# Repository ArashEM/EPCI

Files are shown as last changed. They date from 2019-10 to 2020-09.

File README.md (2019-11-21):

# Introduction

I always had a dream about HW/SW co-design of network controller. Like designing schematic / PCB, then develop FW/SW and so on ...

This is basically just a dream. But for my first iteration I'd decided to design a PCI network card.

As PCI is parallel (and a little simple) protocol, so I can handle (hopefully) hardware part of network card in LX9! 

Again, my design can be as simple as 2 layer PCB. There it  is!

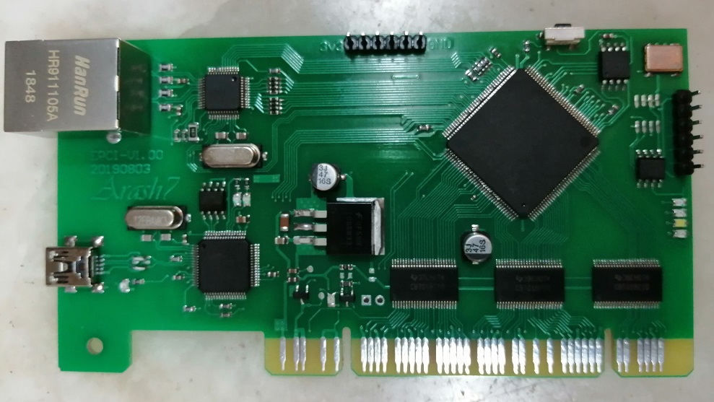
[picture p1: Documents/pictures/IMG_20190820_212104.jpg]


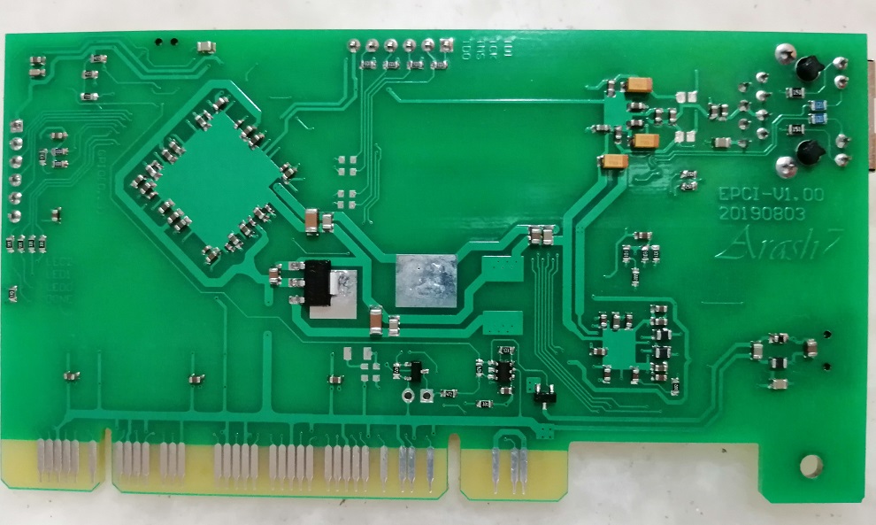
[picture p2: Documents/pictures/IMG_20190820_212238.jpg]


# Specification

First of all, main idea of board came from **MESA-5I25** board from [mesanet.com](http://www.mesanet.com/fpgacardinfo.html). I've learn alot from their board (only it's pictures, I've never have one) and HDLs they provide for board.

- Universal PCI interface (5v0, 3v3)
- XC6SLX9-2TQG144I
- DP83848 (Ethernet PHY with MII interface to FPGA)
- W25Q64FV (32Mb x4 flash)
- FT2232H (As USB to serial and JTAG interface)

# Development 

I'm still working on HDLs. codes on FW/SRC  are simple demo for board functionality which:

- Provide 256 bytes BRAM in **first** 256 bytes of `BAR0`
- Provide 1 byte general output register in **second** 256 bytes of `BAR0` which control 3x LED on board

I've tested MII/MDIO interface via MicroBlaze soft core. They are working.

Here is my development setup:



Motherboard I'm using, is an old `G41M-E2SL` which runs Ubuntu-16.04 from **PXE/NFS**. So I have full control over kernel, initrd and rootfs. 

Check `Documents\pxe-menu` 

# Notes

1. If you want to use this board, as I and my good friend said: **Check it yourself** !
2. And ... Have fun ...

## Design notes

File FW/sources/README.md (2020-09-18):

# Introduction

This folder contains EPCI project firmwares. Which include HDLs for FPGA and C code for Linux device driver.

- `hdl` includes all HDL files to build **BIT** for EPCI-V1.0X board
- `driver` include all C files to build **.ko** file which is EPCI-V1.0X Linux driver

## Synthesis prerequisites 

To build (synthesis / Implement) HDL files, you need:

- Installed <u>Xilinx ISE tools</u>. I've tested HDLs with ISE-14.07 
- Installed <u>GNU make</u> utility 

Then

```bash
git clone https://github.com/ArashEM/EPCI.git
cd EPCI/FW/sources/hdl/
make mcs
```

You can find programming files in `build/epci_fpga.bit` , `build/epci_fpga.mcs`

## Compile prerequisites

To compile EPCI Linux driver, you need:

- Linux headers (According to your Distro. Linux kernel version). I've tested it under Ubuntu-16.04 with kernel *4.4.0-116-generic #140*.
- `gcc`

Then

```bash
git clone https://github.com/ArashEM/EPCI.git
cd EPCI/FW/sources/driver/
make 
```

You can find kernel module in `build/epci.ko`

# How to change

Synthesizing HDLs is based on [ISE-Makefile](https://github.com/duskwuff/Xilinx-ISE-Makefile.git)  project with a little modifications. 

First of all, check `configs/project.cfg` file which include all HDLs and synthesis options. You do not need to make any changes in `Makefile`. 

Kernel module build is traditional Linux Kbuild system. For more information you can check [lkmpg](https://www.tldp.org/LDP/lkmpg/2.6/lkmpg.pdf). 

# Jenkins

`Jenkinsfile` in this directory is about to implement **hardware in loop** tests via two salve node (`ise-0` and `dh-01`). It contains following stages:

1. `checkout` : clone repository in **master** node and stash it for further use
2. `build`: This stage is parallel build stage which compile *kernel module* in **dh-01** node. It also generate *bitfile* in **ise-01** node. I will explain more about these nodes. In this stage some *test applications* are compiled too.
3. `deploy`: This stage deploy build artifacts (*bitfile* and *driver*) in real setup. With help of `openocd` I could program FPGA in Linux. Some scripts are developed for ease of deployment process.
4. `test`: After *bitfile* is loaded to FPGA and device driver is ready to use, test application in run to ensure that whole chain is working fine. 

## slave node `ise-01`

`ise-0` is Windows/Linux  slave (virtual) machine which is used to generate *bitfile*/*mcs* for EPCI-V1.0x FPGA. This node includes:

- Installed <u>Xilinx ISE tools</u>. I've tested HDLs with ISE-14.07 
- Installed <u>GNU make</u> utility 

Make sure Jenkins has proper access to use Xilinx ISE tools. 

## slave node `dh-01`

`dh-0` is Linux **physical** machine with PCI slot which is used to compile device driver and test *EPCI-V1.0x* board. This includes: 

- Linux headers (According to your Distro. Linux kernel version). I've tested it under Ubuntu-16.04 with kernel *4.4.0-116-generic #140*.
- `gcc` : for compiling driver and test applications
- `openocd`: for programming FPGA (check `hdl/scripts/epci-openocd.cfg`). As you know *EPCI-V1.0x* has an on board JTAG (`HS-2`) programmer which is connected to `dh-0` via USB cable 
- `sudoer` access for *jenkins* user (controlled by **master** node) to use `insmod` and `rmmod`  (check `driver/scripts/epci_load`)
- *EPCI-V1.0x* board is installed in one of PCI slot of `dh-01`. 

As you can see `dh-01` is used for build as well as test bed for *EPCI-V1.0x*. It's an **Asus G41M-E2SL** motherboard which I described in project top level `README.md` file.

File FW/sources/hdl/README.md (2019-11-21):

# Introduction

HDL part of project can be found here. File hierarchy is and folder content is described below

- `components`: containing all HDL components of project
- `configs`: includes Makefile configuration files and other configuration files
- `constraints`: UCF and other constraint fils
- `packages`: All required packages for VHDL files to be synthesized 
- `build`: build artifacts like **mcs** file can be found here

# Architecture

EPCI implements only `BAR0` with **64KB** of  non-prefetchable memory space. Here is result of `lspci` command in G41 board

```bash
root@G41MES2L:/home/me# lspci -xxxvv -s 03:01.0
03:01.0 DPIO module: Xilinx Corporation Xilinx 6 Designs (Xilinx IP) (rev 02)
        Subsystem: Xilinx Corporation Xilinx 6 Designs (Xilinx IP)
        Control: I/O- Mem+ BusMaster- SpecCycle- MemWINV- VGASnoop- ParErr- Stepping- SERR- FastB2B- DisINTx-
        Status: Cap- 66MHz- UDF- FastB2B- ParErr- DEVSEL=medium >TAbort- <TAbort- <MAbort- >SERR- <PERR- INTx-
        Interrupt: pin A routed to IRQ 11
        Region 0: Memory at e1500000 (32-bit, non-prefetchable) [size=64K]
00: ee 10 00 06 02 00 00 02 02 00 00 11 00 00 00 00
10: 00 00 50 e1 00 00 00 00 00 00 00 00 00 00 00 00
20: 00 00 00 00 00 00 00 00 00 00 00 00 ee 10 00 06
30: 00 00 00 00 00 00 00 00 00 00 00 00 00 01 00 00

```

## Memory map

Internal memory map of EPCI firmware is described in following table. All offsets are according to `BAR0` address.

| offset | size (B) | description |
| --- | --- | --- |
| `0x0000` | `0x8000` | **32KB** of SRAM. can be used for Read/Write test operation. byte, word and dword access is implemented. |
| `0x8010` | `0x10` | Register map for **LEDs** controller. Details of register is listed below |

##  LED controller 

`EPCI-V1.00` hardware had 3 LEDs. each LED has it's own controller with 32 bit control registers.

| offset | size (B) | description |
| --- | --- | --- |
| `0x0`  | `0x1` | (x,x,x,x,x,x,x, `on/off`). Control LEDx on/off status |
| `0x1`  | `0x1` | For future used |
| `0x2`  | `0x02` | PWM value |

For more information check `hdl/components/LED.vhd`

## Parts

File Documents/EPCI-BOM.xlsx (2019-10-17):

Value | Quantity | Footprint | Description | Designator | Available | Shop
100nF | 17 | 0603PKG | Capacitor | C1, C2, C3, C4, C10, C11, C12, C13, C15, C16, C17, C19, C20, C36, C83, C85, C86 | YES
1.5nF | 1 | C0805 | Capacitor | C5 | YES
27pF | 2 | C0805 | Capacitor | C6, C7 | YES
10uF | 3 | 3216X18N | Polarized Capacitor (Surface Mount) | C8, C9, C14 | YES
1uF | 1 | 0603PKG | Capacitor | C18 | YES
100nF | 9 | C0805 | Capacitor | C21, C22, C25, C29, C33, C34, C35, C81, C88 | YES
10uF | 1 | C0805 | Capacitor | C23 | YES
22uF | 3 | C1206 | Capacitor | C24, C28, C87 | YES
47uf | 2 | Capacitor |  | C26, C27 | YES
100nF | 14 | 0603PKG | Capacitor (Semiconductor SIM Model) | C30, C31, C32, C38, C39, C40, C41, C43, C44, C45, C47, C49, C52, C82 | YES
3.3uF | 1 | C0805 | Capacitor | C37 | NO | JAVAN
10uF | 1 | 0603PKG | Capacitor (Semiconductor SIM Model) | C42 | YES
4.7uF | 20 | 0603PKG | Capacitor (Semiconductor SIM Model) | C46, C48, C54, C55, C56, C57, C58, C59, C60, C62, C63, C64, C67, C68, C69, C70, C75, C76, C79, C80 | NO | IC-KALA
27pF | 2 | 0603PKG | Capacitor | C50, C51 | YES
470n | 10 | 0402 | Capacitor (Semiconductor SIM Model) | C53, C61, C65, C66, C71, C72, C73, C74, C77, C78 | NO | IC-KALA
47nF | 1 | 0603PKG | Capacitor | C84 | YES
 | 8 | C0805 | Typical INFRARED GaAs LED | D1, D2, D3, D4, D5, D6, D7, D8 | YES
 | 1 | C1206 | Zener Diode | D9 | NO | KA
 | 1 | PCI-32bit-5/3.3V-V2.2 | PCI-32bit-5/3.3V-V2.2 | J1 | YES
10mH | 4 | C0805 | Inductor | L1, L2, L3, L4 | YES
 | 1 | RJ45 |  | LAN1 | YES
 | 1 | HDR1X2 | Header, 2-Pin | P1 | YES
 | 1 | Mini USB |  | P2 | YES
 | 1 | HDR1X6 | Header, 6-Pin | P3 | YES
 | 1 | HDR1X6 | Header, 6-Pin | P4 | YES
 | 2 | SOT23 | N-Channel Power MOSFET | Q1, Q4 | NO | JAVAN | IRLML2502
 | 2 | SOT23 | P-Channel Power MOSFET | Q2, Q3 | NO | JAVAN
0R_DNP | 2 | C0805 | Semiconductor Resistor | R1, R2 | YES
50 | 4 | C0805 | Semiconductor Resistor | R3, R4, R5, R6 | YES
220R | 2 | 0603PKG | Semiconductor Resistor | R7, R51 | NO | JAVAN
120R | 2 | C0805 | Semiconductor Resistor | R8, R9 | YES
220R | 3 | ARA4x0603 |  | R10, R13, R52 | NO | KA
150R | 2 | C0805 | Semiconductor Resistor | R11, R12 | YES
1.5K | 2 | 0603PKG | Semiconductor Resistor | R14, R15 | NO | JAVAN
2.2K | 3 | 0603PKG | Semiconductor Resistor | R16, R17, R38 | NO | JAVAN
4.87K | 1 | C1206 | Semiconductor Resistor | R18 | YES
10K | 12 | 0603PKG | Semiconductor Resistor | R20, R23, R33, R34, R35, R42, R43, R44, R45, R57, R58, R62 | YES
330 | 7 | 0603PKG | Semiconductor Resistor | R21, R30, R36, R37, R59, R60, R61 | YES
470K | 1 | 0603PKG | Semiconductor Resistor | R22 | NO | JAVAN
4.7K | 7 | 0603PKG | Resistor | R24, R25, R40, R53, R54, R55, R56 | YES
22R | 4 | 0603PKG | Semiconductor Resistor | R26, R27, R28, R29 | YES
1K0 | 1 | 0603PKG | Semiconductor Resistor | R31 | YES
12K0 | 1 | 0603PKG | Semiconductor Resistor | R32 | NO | JAVAN
0R | 2 | 0603PKG | Resistor | R39, R64 | YES
330R | 1 | 0603PKG | Resistor | R41 | YES
30R | 1 | 0603PKG | Resistor | R46 | NO | JAVAN | 33R
0R_DNP | 3 | 0603PKG | Resistor | R63, R65, R66 | YES
 | 1 | SMD push button | Switch | S1 | YES
 | 1 | LQFP48 |  | U1 | YES
 | 1 | SOT23-6 | Low Loss PowerPath™ Controller in ThinSOT | U2 | YES
 | 1 | TO263 |  | U3 | YES
 | 1 | SOT223 | 1A Adjustable/Fixed Low Dropout Linear Regulator | U4 | NO | JAVAN | AMS1117
 | 3 | TSSOP-48-DGG | 20-BIT FET BUS SWITCH WITH LEVEL SHIFTING | U5, U6, U7 | YES
 | 1 | SOT457 | TVS Zener | U8 | NO | JAVAN | PRTR5V0U2D
 | 1 | 8S1_N | 1Kbit (128 x 8 or 64 x 16), 3-wire Bus Serial Automotive EEPROM, 2.5V, 8-Pin SOIC, Bulk | U9 | YES
 | 1 | LQFP-64_N | Dual High Speed USB To Multipurpose UART/FIFO IC, 64-pin LQFP, Tape and Reel | U10 | YES
 | 1 | TQG144 | Xilinx Spartan6 LX9 | U11 | YES
 | 1 | SSOP8 | W25Q32FVSSIG | U12 | NO | JAVAN
 | 1 | Crystal5x7 |  | U13 | YES
 | 1 | 8S1_N | Digital Temperature Sensor and Thermal Watchdog with Two-Wire Interface, 8 pin MINI SOIC | U14 | NO | ?
 | 1 | 8S1_N | 1Kbit (128 x 8), 2-wire Bus Automotive Serial EEPROM with Write Protect, 2.5V, 8-Pin SOIC, Bulk | U15 | YES
25Mhz | 1 | SMD_Crystal | Crystal Oscillator | Y1 | NO | JAVAN
12Mhz | 1 | SMD_Crystal | Crystal Oscillator | Y2 | NO | IC-KALA

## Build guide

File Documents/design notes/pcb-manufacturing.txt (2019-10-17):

https://www.slideshare.net/epectec/how-to-build-a-circuit-board-boot-camp

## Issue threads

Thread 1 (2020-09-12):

multiple read from /dev/epci-mem cause BAR0 to clear

ArashEM, 2020-09-12:
While EPCI is working, by multiple reading form `/dev/epci-mem`, BAR0 become `0x00`
Here is evidence for it:
```
root@G41MES2L:~# hexdump -C -n 256 /dev/epci-mem
00000000  00 00 00 00 00 00 00 00  00 00 00 00 00 00 00 00  |................|
*
00000100
root@G41MES2L:~# hexdump -C -n 256 /dev/epci-mem
00000000  ff ff ff ff ff ff ff ff  ff ff ff ff ff ff ff ff  |................|
*
00000100
```
After calling `hdl/scripts/epci_configure` everything works fine

ArashEM, 2020-09-12:
By using `pcie_debug`, multiple read from memory cause no problem.
`pcie_debug` use `/sys/bus/pci/devices/0000\:03\:01.0/resource0` to access **BAR0**.
Maybe there is some issue with `/dev/epci-mem`!

ArashEM, 2020-09-13:
Is it sort of **reset**?
Why would `BAR0` become zero during reading via `hexdump`?
At first I should clear problem source
- FPGA firmware
- Kernel driver
- Both!!

ArashEM, 2020-09-13:
This pattern is interesting too
```
root@G41MES2L:/home/me/EPCI/FW/sources/hdl# hexdump /dev/epci-mem
0000000 0000 0000 0000 0000 0000 0000 0000 0000
*
0000380 ffff ffff 0000 0000 ffff ffff ffff ffff
0000390 ffff ffff ffff ffff ffff ffff ffff ffff
*
0008000
```
Seem `BAR0` is some how malfunctioning

ArashEM, 2020-09-13:
And this one too
Healthy:
```
root@G41MES2L:/home/me/EPCI/FW/sources/hdl# hexdump -n 1024 /dev/epci-mem
0000000 e816 f000 e816 f000 e2c3 f000 e816 f000
0000010 e804 f000 ff54 f000 70a8 f000 e816 f000
0000020 fea5 f000 e987 f000 ef6f f000 ef6f f000
0000030 ef6f f000 ef6f f000 ef57 f000 ef6f f000
0000040 0014 c000 f84d f000 f841 f000 ec59 f000
0000050 e739 f000 f859 f000 e82e f000 efd2 f000
0000060 e7a4 f000 e6f2 f000 fe6e f000 ff53 f000
0000070 ff53 f000 f0a4 f000 efc7 f000 7c81 c000
0000080 e816 f000 e816 f000 e816 f000 e816 f000
*
0000100 ec59 f000 87b0 f000 f065 f000 7881 c000
0000110 e816 f000 e816 f000 87b0 f000 e816 f000
0000120 e816 f000 e816 f000 e816 f000 e816 f000
*
0000140 ef6f f000 e816 f000 e816 f000 e816 f000
0000150 e816 f000 e816 f000 e816 f000 e816 f000
*
0000180 0000 0000 0000 0000 0000 0000 0000 0000
*
00001a0 e816 f000 e816 f000 e816 f000 e816 f000
00001b0 e816 f000 0014 c000 e816 f000 e816 f000
00001c0 fcac f000 ecf3 f000 ef6f f000 9f00 f000
00001d0 ee5d f000 f0fc f000 ed00 f000 ed24 f000
00001e0 0000 0000 0000 0000 0000 0000 0000 0000
*
0000360 0000 0000 0000 0000 0000 743e 44c3 eee7
0000370 fed1 e806 0001 1000 0000 038e 0000 eee7
0000380 1801 0f00 0050 0601 0700 7626 1800 1800
0000390 d000 0050 03d4 0000 fed1 43da 0001 00ff
00003a0 0000 0001 f880 0007 d000 0e0a 0000 0260
00003b0 d000 0246 0000 fca0 f000 fca3 0670 0000
00003c0 9800 0707 d000 0212 0040 0000 0cd0 005e
00003d0 0000 0000 f000 f000 0050 0000 43da 0000
00003e0 00ff 0000 f8d8 0cd0 0cd3 4451 f000 0802
00003f0 43da 4420 50aa 477d 4603 0809 4524 0009
0000400
```
Malfunctioning
```
root@G41MES2L:/home/me/EPCI/FW/sources/hdl# hexdump -n 1024 /dev/epci-mem
0000000 e816 f000 e816 f000 e2c3 f000 e816 f000
0000010 e804 f000 ff54 f000 70a8 f000 e816 f000
0000020 fea5 f000 e987 f000 ef6f f000 ef6f f000
0000030 ef6f f000 ef6f f000 ef57 f000 ef6f f000
0000040 0014 c000 f84d f000 f841 f000 ec59 f000
0000050 e739 f000 f859 f000 e82e f000 efd2 f000
0000060 e7a4 f000 e6f2 f000 fe6e f000 ff53 f000
0000070 ff53 f000 f0a4 f000 efc7 f000 7c81 c000
0000080 e816 f000 e816 f000 e816 f000 e816 f000
*
0000100 ec59 f000 87b0 f000 f065 f000 7881 c000
0000110 e816 f000 e816 f000 87b0 f000 e816 f000
0000120 e816 f000 e816 f000 e816 f000 e816 f000
*
0000140 ef6f f000 e816 f000 e816 f000 e816 f000
0000150 e816 f000 e816 f000 e816 f000 e816 f000
*
0000180 0000 0000 0000 0000 0000 0000 0000 0000
*
00001a0 e816 f000 e816 f000 e816 f000 e816 f000
00001b0 e816 f000 0014 c000 e816 f000 e816 f000
00001c0 fcac f000 ecf3 f000 ef6f f000 9f00 f000
00001d0 ee5d f000 f0fc f000 ed00 f000 ed24 f000
00001e0 0000 0000 0000 0000 0000 0000 0000 0000
*
0000300 ffff ffff 0000 0000 ffff ffff ffff ffff
0000310 ffff ffff ffff ffff ffff ffff ffff ffff
*
0000400
```
It always happen around address **0x300**

ArashEM, 2020-09-13:
It's behavior is random.
I mean sometimes after 20 time of read, **BAR0** is still `0xe1500000`.
Sometimes at first read, **BAR0** become **0**.

ArashEM, 2020-09-13:
As **BRAM** content is preserved after cleaning **BAR0**, there is no `reset` issue

ArashEM, 2020-09-14:
What if reading from `/sys/bus/pci/devices/0000\:03\:01.0/resource0` does not initiate a PCI transaction?!
As it's **pre fetch able** memory area.
But using `/dev/epci-mem` cause a real PCI transaction and cause some sort of HW issue which lead to clearing **BAR0**

ArashEM, 2020-09-17:
Testing with `tests/mem/mem_bt.c` show no error!
But still `hexdump` cause that error!
I'm going to test it for long time!

ArashEM, 2020-09-17:
Here is long term test results:
```
me@G41MES2L:~/EPCI/FW/sources/tests/mem$ time ./run_mem_bt.sh 35000
Error in address:0x00000be4
Read  value:0x16
Write value:0x35
Error in address:0x00000be5
Read  value:0x5f
Write value:0x5c
Error in address:0x00000be6
Read  value:0x69
Write value:0xffffff90
Error in address:0x00000be7
Read  value:0xfffffffe
Write value:0x3a
error in iteration 17947
Error in address:0x00002828
Read  value:0xffffffff
Write value:0x00
Error in address:0x00002829
Read  value:0xffffffff
Write value:0xffffff80
Error in address:0x0000282a
Read  value:0xffffffff
Write value:0x01
Error in address:0x0000282b
Read  value:0xffffffff
Write value:0x00
Error in address:0x0000282c
Read  value:0xffffffcc
Write value:0xffffffed
Error in address:0x0000282d
Read  value:0xffffff95
Write value:0xffffffed
Error in address:0x0000282e
Read  value:0xffffffec
Write value:0xffffffa6
Error in address:0x0000282f
Read  value:0x1e
Write value:0x17
error in iteration 26749
Total iteration: 35000
Total errors: 2

real    64m25.501s
user    0m49.748s
sys     1m57.416s
```
In 35000 iteration only 2 error occurs!
So what's wrong with `hexdump`?

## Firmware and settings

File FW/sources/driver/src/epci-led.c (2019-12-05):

/**
*	epci led handler
*	Copyright (C) 2019	arash.golgol@gmail.com
*
*/

#include <linux/kernel.h>
#include <linux/pci.h>
#include <linux/leds.h>
#include "epci.h"


/**
*	epci led information
*/
struct led_info epci_led_info[] = {
	{
		.name = "d1:blue",
		.default_trigger = "none",
	},
	{
		.name = "d2:green",
		.default_trigger = "heartbeat",
	},
	{
		.name = "d3:red",
		.default_trigger = "default-on",
	}

};

struct led_platform_data epci_led_pdata = {
	.num_leds = ARRAY_SIZE(epci_led_info),
	.leds = epci_led_info,
};

/**
*	set PWM
*/
static void epci_set_pwm(struct epci_led *led)
{
	unsigned long  offset  = (led->led_num) << 2;	/* each led has 4 bytes register */
	void __iomem *led_addr = led->board->base + 		
				 led->board->info->led_offset +
				 offset;
	iowrite32(0xFFFF0000, led_addr);	/*set PWM to 0xFFFF */
}

/**
*
*/
static void epci_led_brightness_set(struct led_classdev *led_cdev, 
	enum led_brightness brightness)
{
	struct epci_led *led = 
		container_of(led_cdev, struct epci_led, led_cdev);
	unsigned long  offset  = (led->led_num) << 2;
	void __iomem *led_addr = led->board->base + 		
							led->board->info->led_offset +
							offset;

	switch(brightness) {
	case LED_FULL:
		iowrite8(0x01, led_addr);
		break;
	case LED_OFF:
		iowrite8(0x00, led_addr);
		break;
	default:
		iowrite8(0x00, led_addr);
		break;
	}
}


int  epci_leds_register(struct epci_priv * board)
{
	struct  epci_led *leds = NULL;
	struct  pci_dev  *dev = board->pdev;
	int		num_leds = epci_led_pdata.num_leds;
	int		i,ret = 0;

	leds = devm_kzalloc(&dev->dev, num_leds*sizeof(*leds), GFP_KERNEL);
	if(!leds) 
		return -ENOMEM;
	
	board->leds = leds;
	
	for(i=0; i < num_leds; i++) {
		leds[i].led_num = i;
		leds[i].board = board;
		
		snprintf(leds[i].name, sizeof(leds[i].name),
				"epci:%s",
				 epci_led_pdata.leds[i].name);
		
		leds[i].led_cdev.default_trigger = 
				epci_led_pdata.leds[i].default_trigger;
		leds[i].led_cdev.name = leds[i].name;
		leds[i].led_cdev.brightness_set = epci_led_brightness_set;
		
		epci_set_pwm(&leds[i]);		/* turn led off and set PWM to max */
		
		ret = led_classdev_register(&dev->dev, &leds[i].led_cdev);
		if(ret < 0) {
			dev_err(&dev->dev, 
				"led class device registeration failed\n");
		goto error_register;
		} 	
	}

	return 0;	
	
error_register:
	while(i--)
		led_classdev_unregister(&leds[i].led_cdev);
	
	return ret;
}

void epci_leds_unregister(struct epci_priv * board)
{
	int		num_leds = epci_led_pdata.num_leds;
	struct  epci_led *leds = board->leds;
	int 	i=0;
	
	for(i=0; i < num_leds; i++)
		led_classdev_unregister(&leds[i].led_cdev);
}

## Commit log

2019-10-17 Intial commit
    [Block Diagram.SchDoc, Bus-switch.SchDoc, EPCI-BOM.xlsx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]
2019-10-27 remove unused LOG file for PCB project
    [Network.CSV]
2019-10-29 Change driver Makfile to have all build objects in build directory. This build dir is added to gitignore too.
2019-10-29 Create a skelton for PCI driver
2019-11-01 probe/remove functions are functionl now.
2019-11-01 enable pci device after initialization is done use constant for device name and number of minors remove unused devno part from epci private data structure
2019-11-02 Map I/O region to be accesible for read/write in driver
2019-11-06 semi functional makefile for building bit file from HDLs
    [project.cfg]
2019-11-06 Add new rule to create MCS file from BIT file
    [project.cfg]
2019-11-06 Add rest of options. Now BIN file from Makfile based project and ISE project are exactly the same (md5sum)
    [project.cfg]
2019-11-15 Add LED register interface. LED drivers and how registers are going to be used are not added yet
    [project.cfg]
2019-11-15 Drive LEDs with for-generate loop. Each LED has 32 bit register which - bit 0 : On/Off - bit 15 to 8 : PWM (Not implemented yet)
2019-11-16 Add I2C/UART pins to top level and UCF
2019-11-21 Add PWM controller. Each LED has 4 byte register for it's control
    [project.cfg]
2019-11-21 Add firmware version in 0x40 offset in configuration space 0x40 -> 16 bit build number 0x42 -> 8 bit minor number 0x43 -> 8 bit major number
    [project.cfg]
2019-11-21 Read and print fw version in epci driver
2019-11-23 change order of registeration in probe function for better work flow
2019-11-23 draft for led brightness in epci device
2019-11-23 working led but horribly coded!
2019-11-25 Create a header file for private data structure. each part of EPCI-V1.0X board will be handled with functions in different files
2019-11-25 Move led related functions to epci-led.c
2019-11-28 Trying to register multiple leds according to board information
2019-11-28 Fix set_pwm function to accept epci_led type
    [epci-led.c]
2019-11-28 register 3 led in loop
2019-11-28 Use more meaningful name for led platform data
2020-09-05 Fix small bug in Makefile for driver
2020-09-06 Add synthesis stage for generating MCS/BIT file
2020-09-08 Add required scripts to program EPCI via openocd
    [epci-openocd.cfg]
2020-09-11 parallelized synthesis/build FW synthesis is done in Win7 slave machine (ies-01) Driver build is done in Ubunu slave machine (dh-01)
2020-09-11 Add dummy deploy stage which program FPGA and load kernel module
2020-09-11 Add some scripts to load/unload EPCI driver and firmware (Not tested yet)
2020-09-12 Fix load/unload scripts according to device node name
2020-09-12 resolve EPCI device address according to it's Vendor/Device ID
2020-09-17 Implement llseek in driver and use random in test application
2020-09-17 Add testing stage to Jenkinsfile
2020-09-20 Add uart and fifo draft code for uart interface - FIFO codes are from http://www.nandland.com - UART codes are from https://github.com/jakubcabal/uart-for-fpga
